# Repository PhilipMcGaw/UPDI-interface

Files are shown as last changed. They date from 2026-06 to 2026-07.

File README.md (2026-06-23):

# UPDI-interface




This is a KiCad PCB that breaks out a common USB‑to‑TTL serial adapter (often sold as a “USB to TTL Serial Communication Conversion Module”) into UPDI, UART, and RS‑485 interfaces. The board is meant to sit between your USB adapter and targets such I am using it with my ROV project.

## UART TX/RX swapping (poka‑yoke)

Getting UART TX and RX the wrong way round is easy at design time and painful to fix once the board is built. I have implemented a [poka‑yoke](https://en.wikipedia.org/wiki/Poka-yoke) crossover: two solder bridges  let you route either straight‑through or swapped connections by changing which pads are bridged—no trace cuts or bodge wires. How it works and how to use it in other projects: [UART TX/RX swapping made simple](https://philipmcgaw.com/uart-tx-rx-swapping-made-simple/).

## License

 * Hardware design files in this repository are licensed under the **[CERN Open Hardware Licence v2 — Strongly Reciprocal (CERN-OHL-S-2.0)](https://gitlab.com/ohwr/project/cernohl/-/wikis/uploads/819d71bea3458f71fba6cf4fb0f2de6b/cern_ohl_s_v2.txt)**, an open source hardware license recommended by the [Open Source Hardware Association (OSHWA)](https://oshwa.org/).
 * Software files in this repository are licensed under the **[Creatice Commons - Attribution-NonCommercial-ShareAlike 4.0 International (CC BY-NC-SA 4.0)](https://creativecommons.org/licenses/by-nc-sa/4.0/)**

- **Copyright:** [Philip McGaw](https://philipmcgaw.com/)

You may use, study, modify, and redistribute the sorcecode, schematic and PCB layout under those terms. **Derivative designs must be released under the same license(s).** If you share the design or boards built from it, include a link to the licenses.

## Related links

- [SquashedFly](https://squashedfly.eu/)
- [UART TX/RX swapping made simple](https://philipmcgaw.com/uart-tx-rx-swapping-made-simple/) — poka‑yoke UART symbol and footprints used on this board
- [KiCad](https://www.kicad.org/) — PCB design software

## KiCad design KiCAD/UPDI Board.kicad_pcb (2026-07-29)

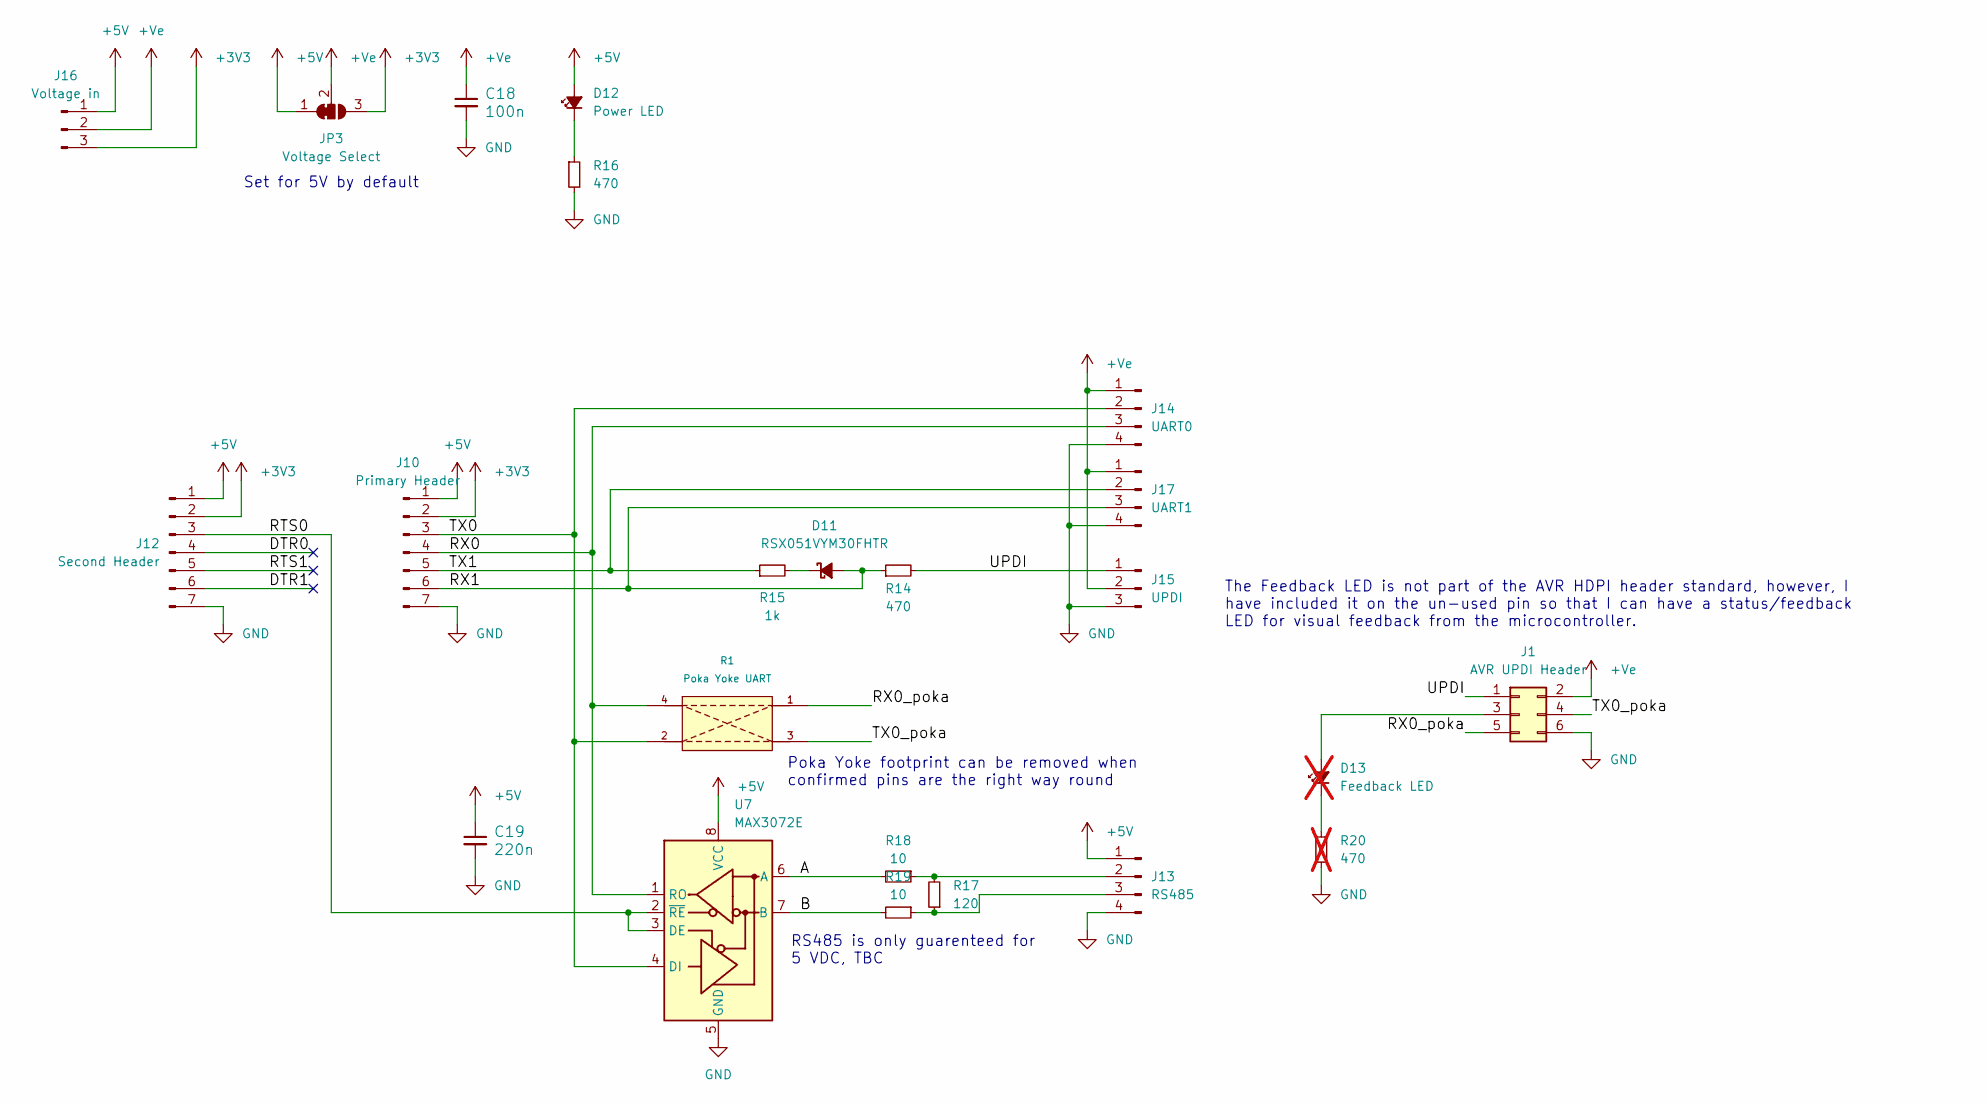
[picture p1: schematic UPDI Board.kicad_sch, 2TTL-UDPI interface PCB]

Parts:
C18: 100n; C_0805_2012Metric_Pad1.18x1.45mm_HandSolder
C19: 220n; C_0805_2012Metric_Pad1.18x1.45mm_HandSolder
D11: RSX051VYM30FHTR; D_SOD-323_HandSoldering
D12: Power LED; LED_0805_2012Metric_Pad1.15x1.40mm_HandSolder
D13: Feedback LED; LED_0805_2012Metric_Pad1.15x1.40mm_HandSolder; not fitted
J1: AVR UPDI Header; PinHeader_2x03_P2.54mm_Vertical
J10: Primary Header; PinSocket_1x07_P2.54mm_Vertical
J12: Second Header; PinSocket_1x07_P2.54mm_Vertical
J13: RS485; PinHeader_1x04_P2.54mm_Vertical
J14: UART0; PinHeader_1x04_P2.54mm_Vertical
J15: UPDI; PinHeader_1x03_P2.54mm_Vertical
J16: Voltage in; PinSocket_1x03_P2.54mm_Vertical
J17: UART1; PinHeader_1x04_P2.54mm_Vertical
JP3: Voltage Select; SolderJumper-3_P1.3mm_Bridged12_Pad1.0x1.5mm_NumberLabels
R1: Poka Yoke UART; Poka yoke UART Solder
R14, R16: 470; R_0805_2012Metric_Pad1.20x1.40mm_HandSolder
R15: 1k; R_0805_2012Metric_Pad1.20x1.40mm_HandSolder
R17: 120; R_0805_2012Metric_Pad1.20x1.40mm_HandSolder
R18, R19: 10; R_0805_2012Metric_Pad1.20x1.40mm_HandSolder
R20: 470; R_0805_2012Metric_Pad1.20x1.40mm_HandSolder; not fitted
U7: MAX3072E; SOIC-8_3.9x4.9mm_P1.27mm

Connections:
+3V3: J10.2, J12.2, J16.3, JP3.3 (B)
+5V: C19.1, D12.2 (A), J10.1, J12.1, J13.1, J16.1, JP3.1 (A), U7.8 (VCC)
+Ve: C18.1, J1.2, J14.1, J15.2, J16.2, J17.1, JP3.2 (C)
/A: R18.2, U7.6 (A)
/B: R19.2, U7.7 (B)
/DTR0: J12.4
/DTR1: J12.6
/RTS0: J12.3, U7.2 (~RE), U7.3 (DE)
/RTS1: J12.5
/RX0: J10.4, J14.3, R1.4, U7.1 (RO)
/RX0_poka: J1.5, R1.1
/RX1: D11.2 (A), J10.6, J17.3, R14.1
/TX0: J10.3, J14.2, R1.2, U7.4 (DI)
/TX0_poka: J1.4, R1.3
/TX1: J10.5, J17.2, R15.1
/UPDI: J1.1, J15.1, R14.2
GND: C18.2, C19.2, J1.6, J10.7, J12.7, J13.4, J14.4, J15.3, J17.4, R16.2, R20.2, U7.5 (GND)
unnamed: D11.1 (K), R15.2
unnamed: D12.1 (K), R16.1
unnamed: D13.2 (A), J1.3
unnamed: D13.1 (K), R20.1
unnamed: J13.2, R17.2, R18.1
unnamed: J13.3, R17.1, R19.1

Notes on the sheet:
Poka Yoke footprint can be removed when confirmed pins are the right way round
Set for 5V by default
RS485 is only guarenteed for 5 VDC, TBC
The Feedback LED is not part of the AVR HDPI header standard, however, I have included it on the un-used pin so that I can have a status/feedback LED for visual feedback from the microcontroller.

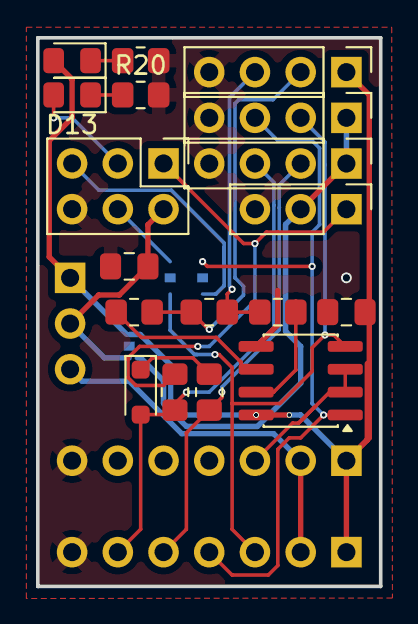
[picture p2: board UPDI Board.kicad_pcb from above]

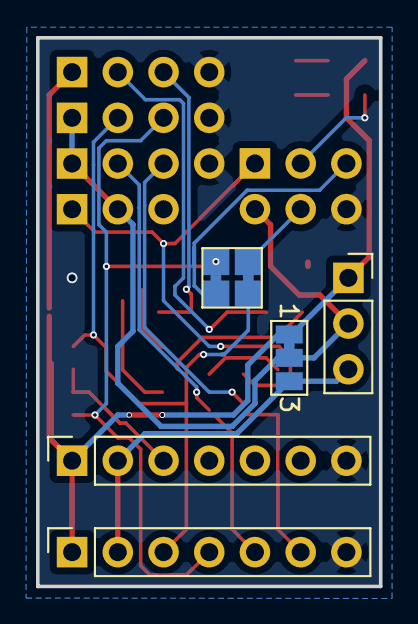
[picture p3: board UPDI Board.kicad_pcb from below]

Board: 2 copper layers, 19.1 x 30.5 mm, 23 parts (5 on the bottom side), 20 nets.

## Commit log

2026-05-26 Uploaded the design files
    [Arduino CAN.kicad_sch, LED - CXA1304.step, LED Cube.kicad_sch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]
2026-05-26 added ground plane
    [UPDI Board.kicad_pcb]
2026-07-24 remove common
    [Arduino CAN.kicad_sch, LED - CXA1304.step, LED Cube.kicad_sch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]
2026-07-29 Clean up and add LED
    [UPDI Board.kicad_pcb, UPDI Board.kicad_sch]
2026-09-01 Update UPDI Board.kicad_sch
    [UPDI Board.kicad_sch]

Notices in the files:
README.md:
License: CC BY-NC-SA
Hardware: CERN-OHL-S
